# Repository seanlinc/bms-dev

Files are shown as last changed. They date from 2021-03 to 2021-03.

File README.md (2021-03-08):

## Battery Management System Dev Board for LTC68xx

This board is original develped for [Spartan Racing Electric](http://sr-e.org), any other FSAE teams and projects are welcome to use

It can directly talk to LTC68xx evaluation board via RJ-45, such as [DC2259A](https://www.analog.com/en/design-center/evaluation-hardware-and-software/evaluation-boards-kits/dc2259a.html)

MIT license, you can use or modify it as you want

### Features
* STM32F303CC6 Microcontroller
* LTC6820 Isoalted SPI interface and transformer
* TI SN65HVD232 CAN transceiver
* CP2012 USB to UART bridge
* On board DB9 connector and termination resistor
* RJ-45 connector for LTC68xx dev board
* USB-C

**About Manufacturing**

It's a 4 layers 50mm x 50mm board, which can be printed in JLC PCB cheaply in case you don't have a sponsorship

The smallest SMD size is 0603, it is designed for hand soldering and reworking

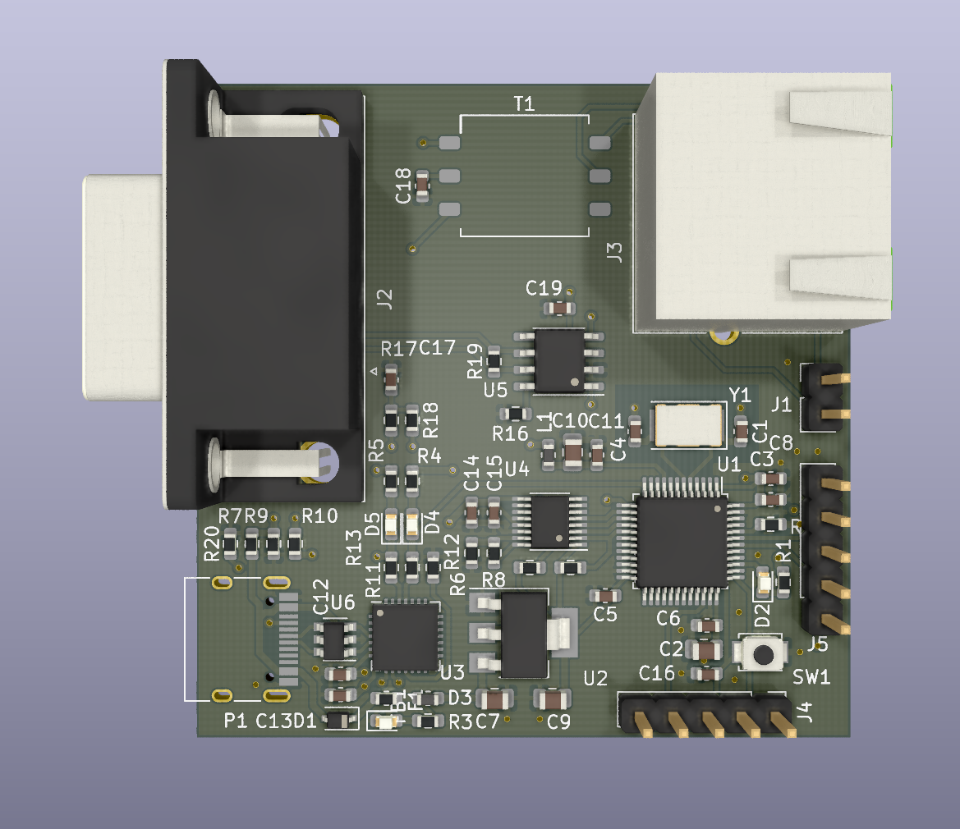
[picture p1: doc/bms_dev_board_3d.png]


Schematic
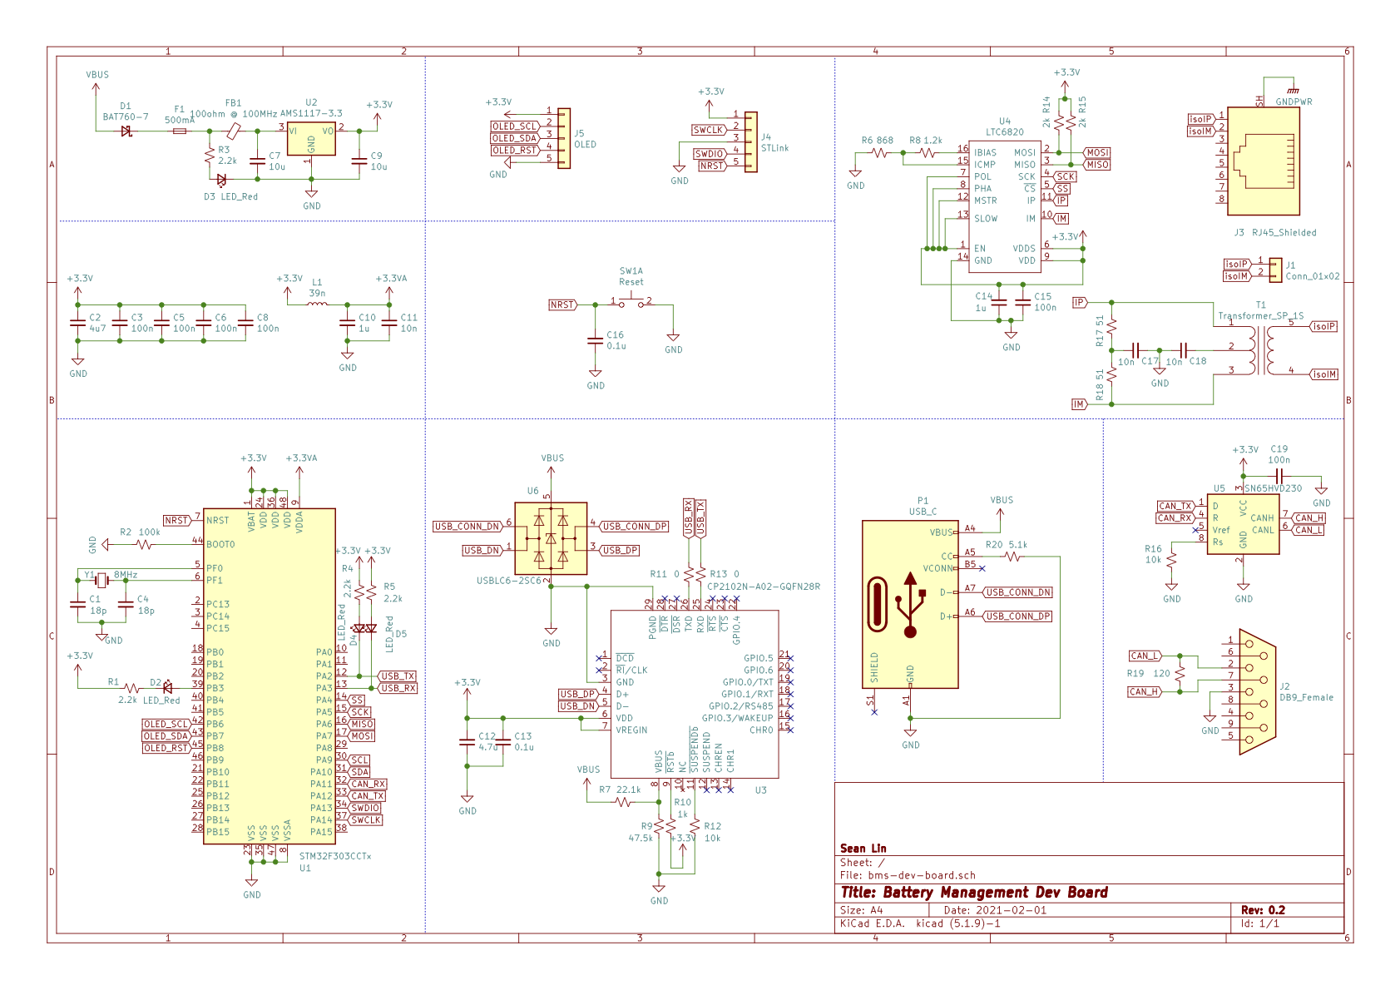
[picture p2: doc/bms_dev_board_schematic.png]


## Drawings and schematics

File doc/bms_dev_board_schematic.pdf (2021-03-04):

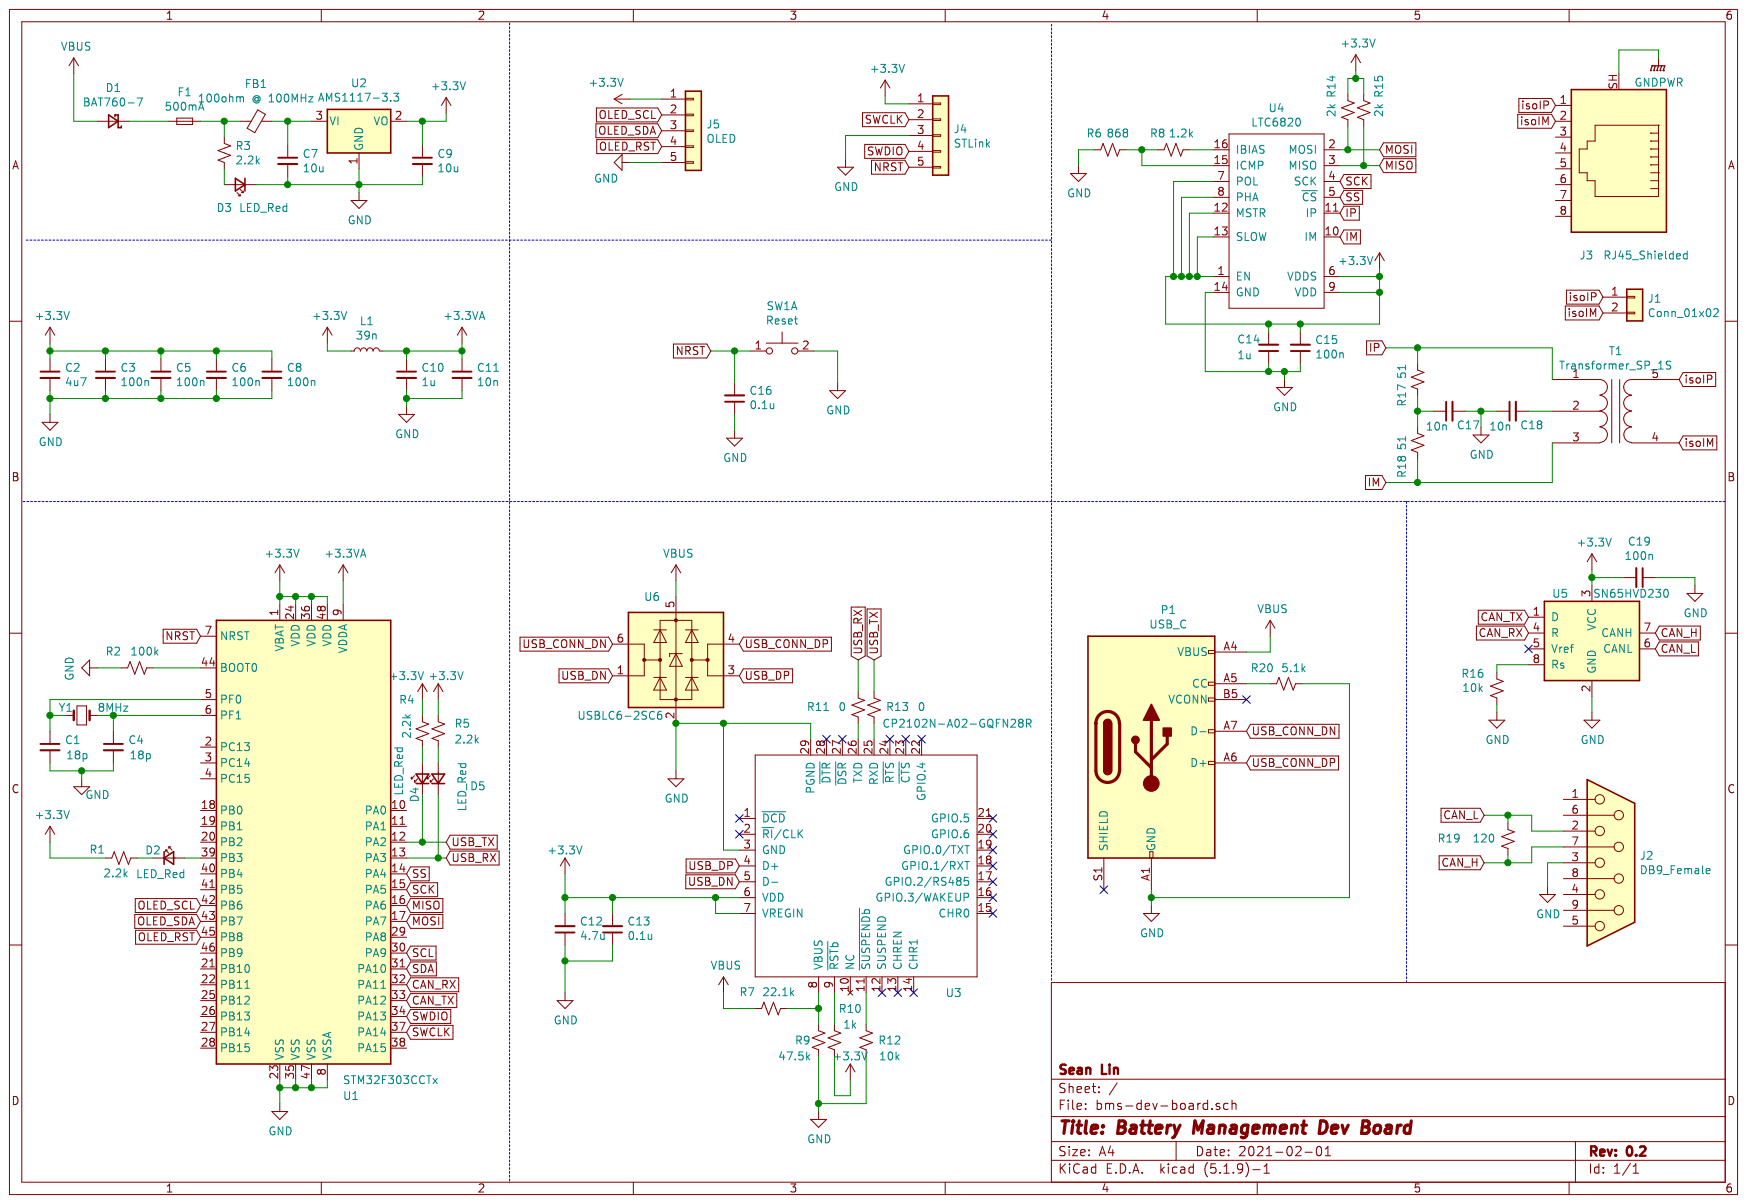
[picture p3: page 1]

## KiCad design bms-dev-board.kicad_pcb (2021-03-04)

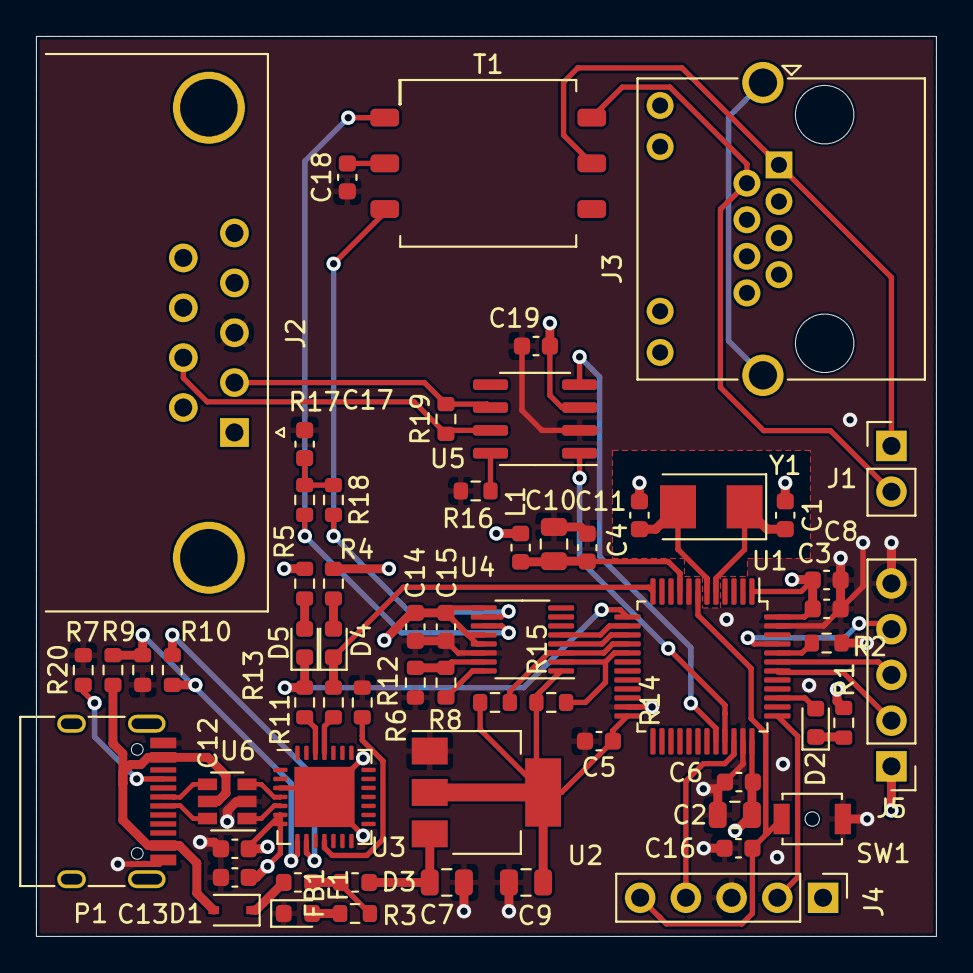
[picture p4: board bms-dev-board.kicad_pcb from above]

Board: 4 copper layers, 50.0 x 50.0 mm, 62 parts (0 on the bottom side), 50 nets.

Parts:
C1, C4: 18p; C_0603_1608Metric
C2: 4u7; C_0805_2012Metric
C3, C5, C6, C8, C15, C19: 100n; C_0603_1608Metric
C7, C9: 10u; C_0805_2012Metric
C10: 1u; C_0805_2012Metric
C11, C17, C18: 10n; C_0603_1608Metric
C12: 4.7u; C_0603_1608Metric
C13, C16: 0.1u; C_0603_1608Metric
C14: 1u; C_0603_1608Metric
D1: BAT760-7; D_SOD-323
D2, D3, D4, D5: LED_Red; LED_0603_1608Metric
F1: 500mA; Fuse_0603_1608Metric
FB1: 100ohm @ 100MHz; L_0603_1608Metric
J1: Conn_01x02; PinHeader_1x02_P2.54mm_Vertical
J2: DB9_Female; DSUB-9_Female_Horizontal_P2.77x2.84mm_EdgePinOffset7.70mm_H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
J3: RJ45_Shielded; RJ45_Amphenol_RJHSE538X
J4: STLink; PinHeader_1x05_P2.54mm_Vertical
J5: OLED; PinHeader_1x05_P2.54mm_Vertical
L1: 39n; L_0603_1608Metric
P1: USB_C; USB_C_Receptacle_HRO_TYPE-C-31-M-12
R1, R3, R4, R5: 2.2k; R_0603_1608Metric
R2: 100k; R_0603_1608Metric
R6: 868; R_0603_1608Metric
R7: 22.1k; R_0603_1608Metric
R8: 1.2k; R_0603_1608Metric
R9: 47.5k; R_0603_1608Metric
R10: 1k; R_0603_1608Metric
R11, R13: 0; R_0603_1608Metric
R12, R16, R19: 10k; R_0603_1608Metric
R14, R15: 2k; R_0603_1608Metric
R17, R18: 51; R_0603_1608Metric
R20: 5.1k; R_0603_1608Metric
SW1: Reset; SW_SPST_B3U-1000P-B
T1: Transformer_SP_1S; Transformer_Murata_78250JC
U1: STM32F303CCTx; LQFP-48_7x7mm_P0.5mm
U2: AMS1117-3.3; SOT-223-3_TabPin2
U3: CP2102N-A02-GQFN28R; QFN-28-1EP_5x5mm_P0.5mm_EP3.35x3.35mm
U4: LTC6820; MSOP-16_3x4.039mm_P0.5mm
U5: SN65HVD230; SOIC-8_3.9x4.9mm_P1.27mm
U6: USBLC6-2SC6; SOT-23-6
Y1: 8MHz; Crystal_SMD_5032-2Pin_5.0x3.2mm

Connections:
+3.3VA: C10.1, C11.1, L1.2, U1.9
+3V3: C2.1, C3.1, C5.1, C6.1, C8.1, C9.1, C12.2, C13.2, C14.2, C15.2, C19.2, J4.1, J5.1, L1.1, R1.1, R4.1, R5.1, R10.2, R14.2, R15.2, U1.1, U1.24, U1.36, U1.48, U2.2, U3.6, U3.7, U4.1, U4.6, U4.7, U4.8, U4.9, U4.12, U4.13, U5.3
CAN_H: J2.7, R19.1, U5.7
CAN_L: J2.2, R19.2, U5.6
CAN_RX: U1.32, U5.4
CAN_TX: U1.33, U5.1
GND: C1.2, C2.2, C3.2, C4.2, C5.2, C6.2, C7.2, C8.2, C9.2, C10.2, C11.2, C12.1, C13.1, C14.1, C15.1, C16.1, C17.2, C18.1, C19.1, D3.1, J2.3, J4.3, J5.5, P1.A1, P1.A12, P1.B1, P1.B12, R2.1, R6.1, R9.2, R12.2, R16.1, R20.1, SW1.2, U1.8, U1.23, U1.35, U1.47, U2.1, U3.3, U3.29, U4.14, U5.2, U6.2
IM: R18.2, T1.3, U4.10
IP: R17.1, T1.1, U4.11
MISO: R15.1, U1.16, U4.3
MOSI: R14.1, U1.17, U4.2
NRST: C16.2, J4.5, SW1.1, U1.7
unnamed: C1.1, U1.5, Y1.1
unnamed: C4.1, U1.6, Y1.2
unnamed: C7.1, FB1.1, U2.3
unnamed: C17.1, R17.2, R18.1
unnamed: C18.2, T1.2
unnamed: D1.1, F1.1
unnamed: D2.1, R1.2
unnamed: D2.2, U1.39
unnamed: D3.2, R3.2
unnamed: D4.2, R4.2
unnamed: D5.2, R5.2
unnamed: F1.2, FB1.2, R3.1
unnamed: P1.A5, R20.2
unnamed: R2.2, U1.44
unnamed: R6.2, R8.1, U4.15
unnamed: R7.2, R9.1, U3.8
unnamed: R8.2, U4.16
unnamed: R10.1, U3.9
unnamed: R11.1, U3.26
unnamed: R12.1, U3.11
unnamed: R13.1, U3.25
unnamed: R16.2, U5.8
OLED_RST: J5.4, U1.45
OLED_SCL: J5.2, U1.42
OLED_SDA: J5.3, U1.43
SCK: U1.15, U4.4
SS: U1.14, U4.5
SWCLK: J4.2, U1.37
SWDIO: J4.4, U1.34
USB_CONN_DN: P1.A7, U6.6
USB_CONN_DP: P1.A6, U6.4
USB_DN: U3.5, U6.1
USB_DP: U3.4, U6.3
USB_RX: D5.1, R11.2, U1.13
USB_TX: D4.1, R13.2, U1.12
VBUS: D1.2, P1.A4, P1.A9, P1.B4, P1.B9, R7.1, U6.5
isoIM: J1.2, J3.2, T1.4
isoIP: J1.1, J3.1, T1.5

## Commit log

2021-03-04 Upload design files
    [bms-dev-board.kicad_pcb, bms-dev-board.sch]
2021-03-08 Add picture for schematic
